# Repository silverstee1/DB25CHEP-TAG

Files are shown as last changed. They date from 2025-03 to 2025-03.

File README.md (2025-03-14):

# DB25CHEP-TAG
Cheap DB25 Parallel Port JTAG Programmer for IDE-EXI, USB Gecko and other XC95XX CPLD projects

Used on Xilinx Webpack ISE software suite to program the CPLD, I use version 13.3 in windows XP but it should work with any version that still supports Parallel cable 3

When using with Xilinx Impact under cable options choose Parallel cable 3

USB-C is only to provide power to the 3.3V regulator for the programmer/CPLD, the R3 and R4 5.1kOhm Resistors can be left out if you'll only be using a USB-C to A cable, they're only necessary with a C to C cable.

A nice 6pin Clip makes it easier to program most CPLDs that have 2.54mm pin JTAG headers on the pcb boards

I use this 6P clip https://www.aliexpress.us/item/3256805030490716.html 

ChepTag+Clip

ISE

20250311_201530-min

20250311_201654-min

20250311_201556-min

20250311_201336-min

pcbnew_kPza4i9rMK

pcbnew_wi8KQkt55a

# CHEP-TAG BOM

When Ordering/uploading the PCB gerbers to ex. JLCPCB I'd recommend to use 1.6mm thickness. The rest of the options can be default.

**U1:** <ins>AMS1117-3.3 SOT-223</ins>

DigiKey Part#: 5399-AMS1117-3.3SOT-223CT-ND

LCSC Part#: C426566

**C1, C2:** <ins>1206 10uF Tantalum Capacitors, + on PCB indicates the Stripe anode side of the cap</ins>

Digikey Part#: 718-TMCMA1C106KTRFCT-ND

LCSC Part#: C4988312

**D1:** <ins>1206 Blue 5ma LED, Led Green side Cathode orientation Marked with a Dot on pcb.</ins>

Digikey Part#: 2007-BL-HB333Q-AV-TRBCT-ND

LCSC Part#: C434440

Aliexpress Link: 1206 Blue https://www.aliexpress.us/item/3256805993208379.html

**R1:** <ins>4.7Kohm 1206 Resistor</ins>

Digikey Part#: 311-4.70KFRCT-ND

LCSC Part#: C137262

**R2:** <ins>10Rohm 1206 Resistor</ins>

Digikey Part#: 311-10.0FRCT-ND

LCSC Part#: C108080

**R3, R4:** <ins>5.1Kohm 0402 Resistors, (only necessary if you want to use USB-C to C cables can be unpopulated if using USB-C to A)</ins>

Digikey Part#: 311-5.1KJRCT-ND

LCSC Part#: C105873

**J1:** <ins>DB25 Male Right Angle Connector</ins>

Digikey Part#: A32100-ND

LCSC Part#: C305948

A cheap option is this 25P Male from Aliexpress https://www.aliexpress.us/item/3256805300852948.html?

remove the screw posts, and solder the front metal faceplate through the post holes filling the holes with lots of solder to the metal rear threads on the back to keep it in place, use plenty of Flux to help the solder stick to the metal.

**J2:** <ins>2.54mm 01x02 Male Pinheader (can be unpopulated, used as external +5V supply input to board instead of USB-C)</ins>

Can be found on Amazon, Ebay, Aliexpress etc. in any length just snip off however much you need.

Example Aliexpress Link https://www.aliexpress.us/item/3256807383526945.html

**J3:** <ins>2.54mm 01x06 Male Pinheader (can use either vertical or right angle 2.54mm header depending on preference)</ins>

Can be found on Amazon, Ebay, Aliexpress etc. in any length just snip off however much you need. 

Example Aliexpress link https://www.aliexpress.us/item/3256807383526945.html

**J5:** <ins>USB-C Female Connector</ins>

Digikey Part#: 52-USB-CB16HTBTRCT-ND

LCSC Part#: C165948

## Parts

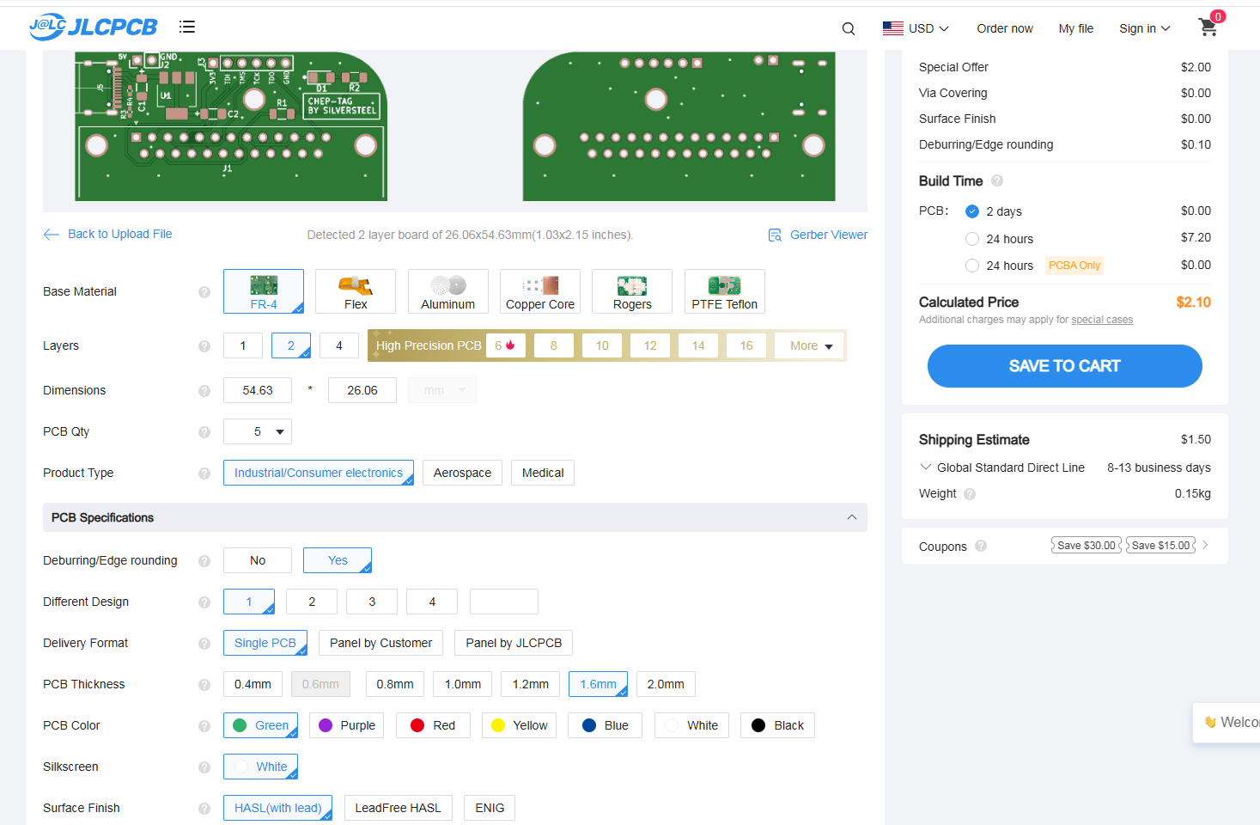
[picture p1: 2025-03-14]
pcb/sample order JLCPCB.png

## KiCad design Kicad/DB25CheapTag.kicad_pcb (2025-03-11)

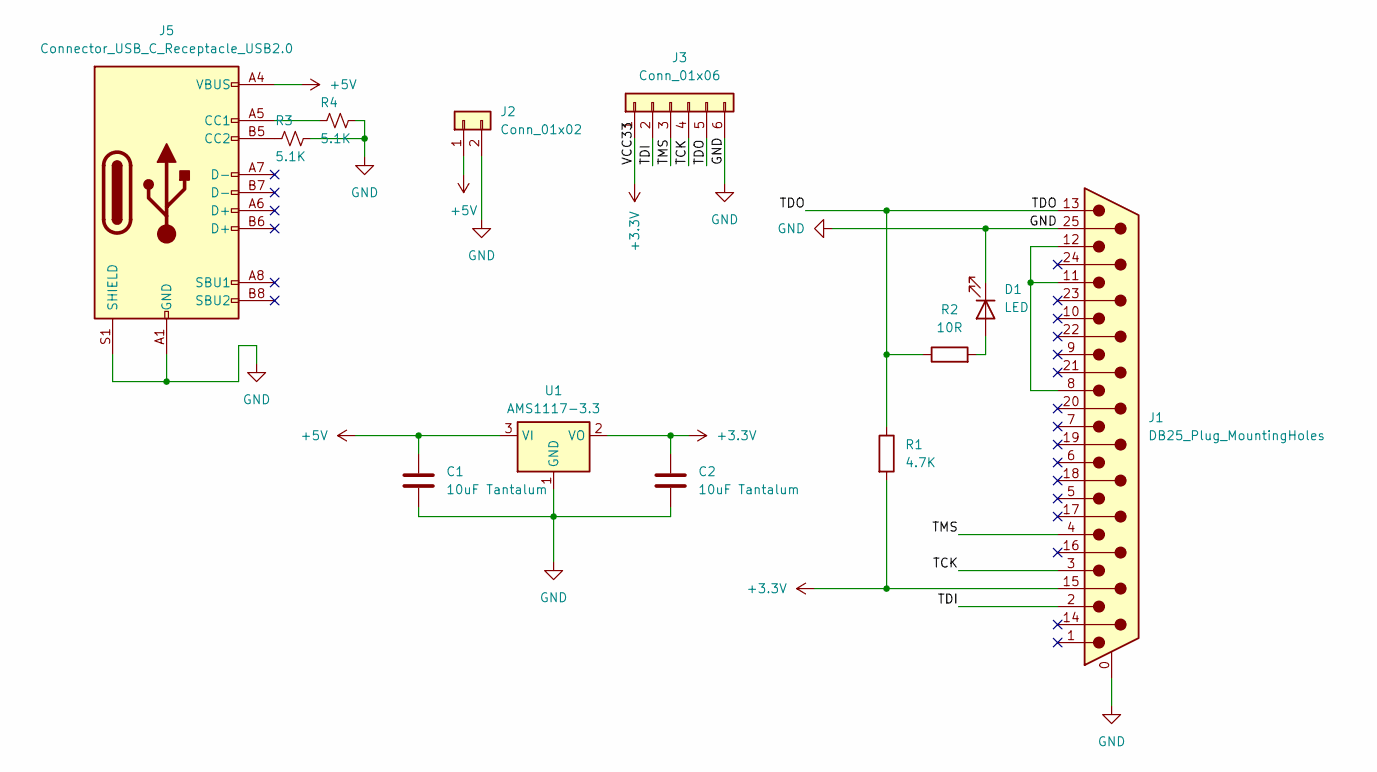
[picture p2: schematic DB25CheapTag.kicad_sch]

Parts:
C1, C2: 10uF Tantalum; C_1206_3216Metric_Pad1.33x1.80mm_HandSolder
D1: LED; LED_1206_3216Metric_Pad1.42x1.75mm_HandSolder
J1: DB25_Plug_MountingHoles; DSUB-25_Male_Horizontal_P2.77x2.84mm_EdgePinOffset7.70mm_Ho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
J2: Conn_01x02; PinHeader_1x02_P2.54mm_Vertical
J3: Conn_01x06; PinHeader_1x06_P2.54mm_Vertical
J5: Connector_USB_C_Receptacle_USB2.0; TYPE-C-31-M-12
R1: 4.7K; R_1206_3216Metric_Pad1.30x1.75mm_HandSolder
R2: 10R; R_1206_3216Metric_Pad1.30x1.75mm_HandSolder
R3, R4: 5.1K; R_0402_1005Metric_Pad0.72x0.64mm_HandSolder
U1: AMS1117-3.3; SOT-223-3_TabPin2

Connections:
+3.3V: C2.1, J1.15, J3.1, R1.2, U1.2 (VO)
+5V: C1.1, J2.1, J5.A4 (VBUS), J5.A9 (VBUS), J5.B4 (VBUS), J5.B9 (VBUS), U1.3 (VI)
/TCK: J1.3, J3.4
/TDI: J1.2, J3.2
/TDO: J1.13, J3.5, R1.1, R2.1
/TMS: J1.4, J3.3
GND: C1.2, C2.2, D1.1 (K), J1.0 (PAD), J1.25, J2.2, J3.6, J5.A1 (GND), J5.A12 (GND), J5.B1 (GND), J5.B12 (GND), J5.S1 (SHIELD), R3.1, R4.1, U1.1 (GND)
unnamed: D1.2 (A), R2.2
unnamed: J1.8, J1.11, J1.12
unnamed: J5.A5 (CC1), R4.2
unnamed: J5.B5 (CC2), R3.2

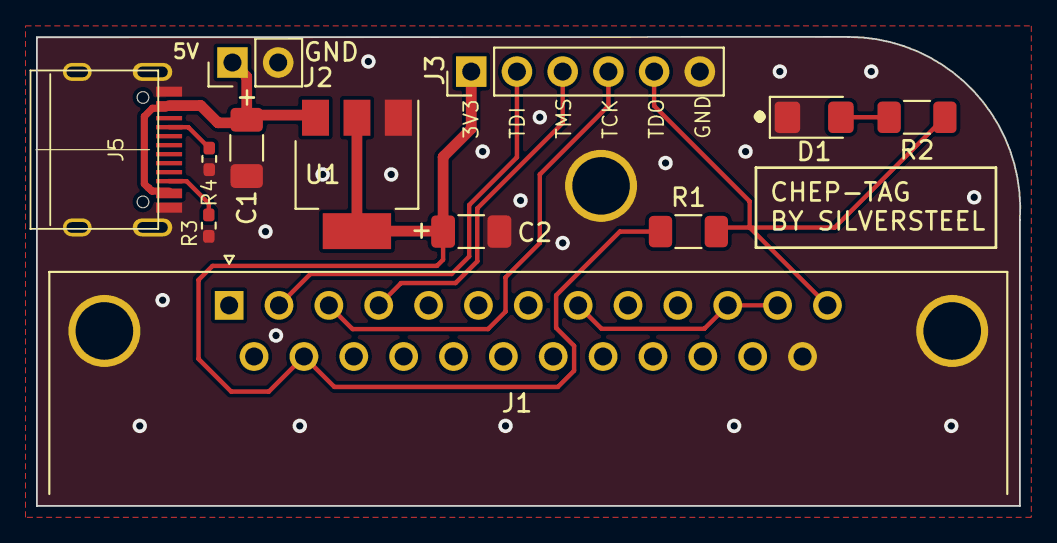
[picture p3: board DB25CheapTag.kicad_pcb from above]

Board: 2 copper layers, 54.6 x 26.1 mm, 12 parts (0 on the bottom side), 11 nets.

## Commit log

2025-03-11 added pcb gerbers
2025-03-11 Add files via upload
    added Kicad Project
    [DB25CheapTag.kicad_pcb, DB25CheapTag.kicad_sch]
